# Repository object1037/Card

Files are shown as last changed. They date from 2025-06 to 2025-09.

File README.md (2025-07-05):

# Card

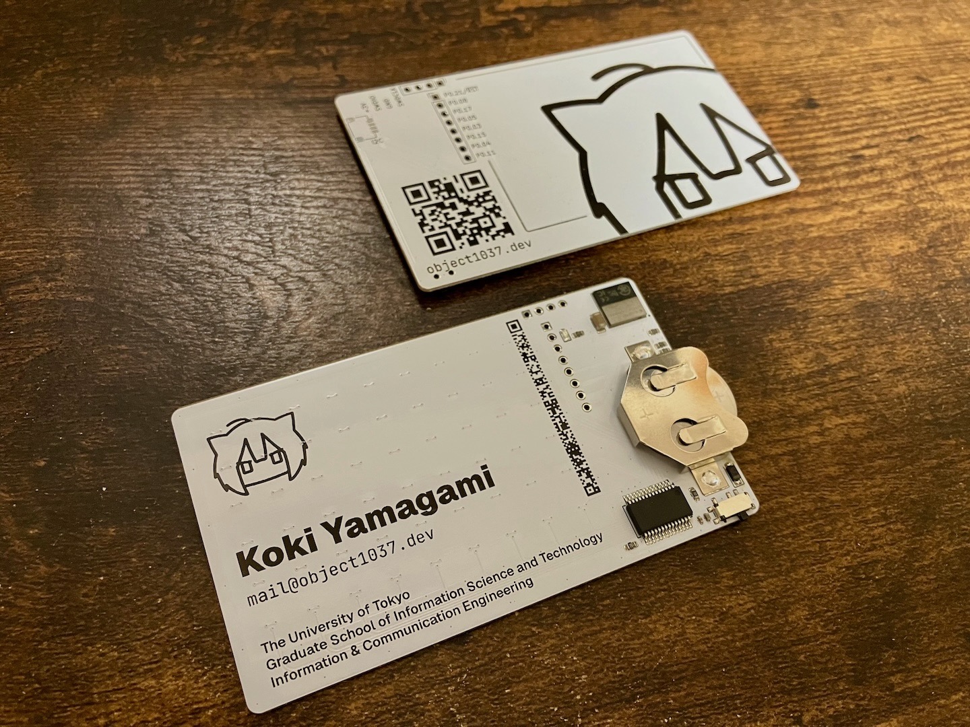
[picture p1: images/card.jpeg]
Photo of assembled cards


A PCB business card that functions as a Bluetooth trackpad.

* BLE module: [ISP1907-LL](https://www.insightsip.com/products/bluetooth-le-modules/isp1907) (SoC: nRF52811)
* Touch controller: [MTCH6102](https://www.microchip.com/en-us/product/mtch6102)
* Power: CR2032

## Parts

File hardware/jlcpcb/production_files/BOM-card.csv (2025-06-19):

Comment | Designator | Footprint | LCSC | Quantity
SW_SPDT | SW1 | SW_SPDT_PCM12 | C128955 | 1
100u | C3 | C_1206_3216Metric | C15008 | 1
0.1u | C1 | C_0402_1005Metric | C1525 | 1
10u | C2 | C_0402_1005Metric | C15525 | 1
LED | D2 | LED_0603_1608Metric | C2286 | 1
4.7k | R3,R4 | R_0603_1608Metric | C23162 | 2
1.8k | R1,R2 | R_0603_1608Metric | C4177 | 2
20k | R5 | R_0603_1608Metric | C4184 | 1
2.2k | R6 | R_0603_1608Metric | C4190 | 1
ISP1907 | U1 | ISP1907 | C5657569 | 1
MTCH6102 | U2 | SSOP-28_5.3x10.2mm_P0.65mm | C641630 | 1

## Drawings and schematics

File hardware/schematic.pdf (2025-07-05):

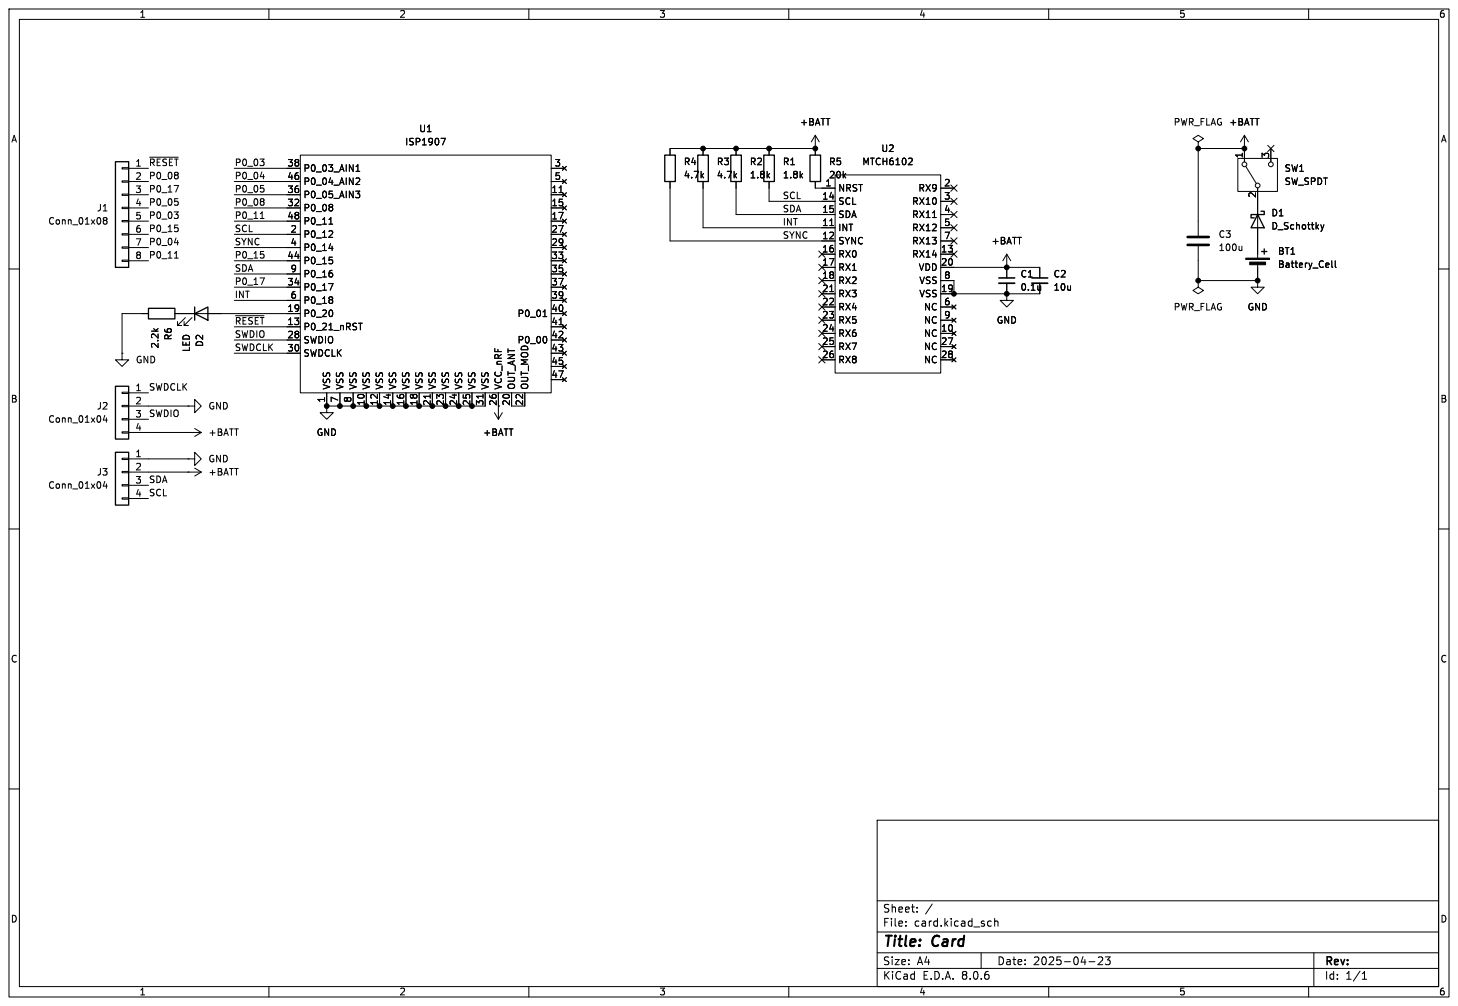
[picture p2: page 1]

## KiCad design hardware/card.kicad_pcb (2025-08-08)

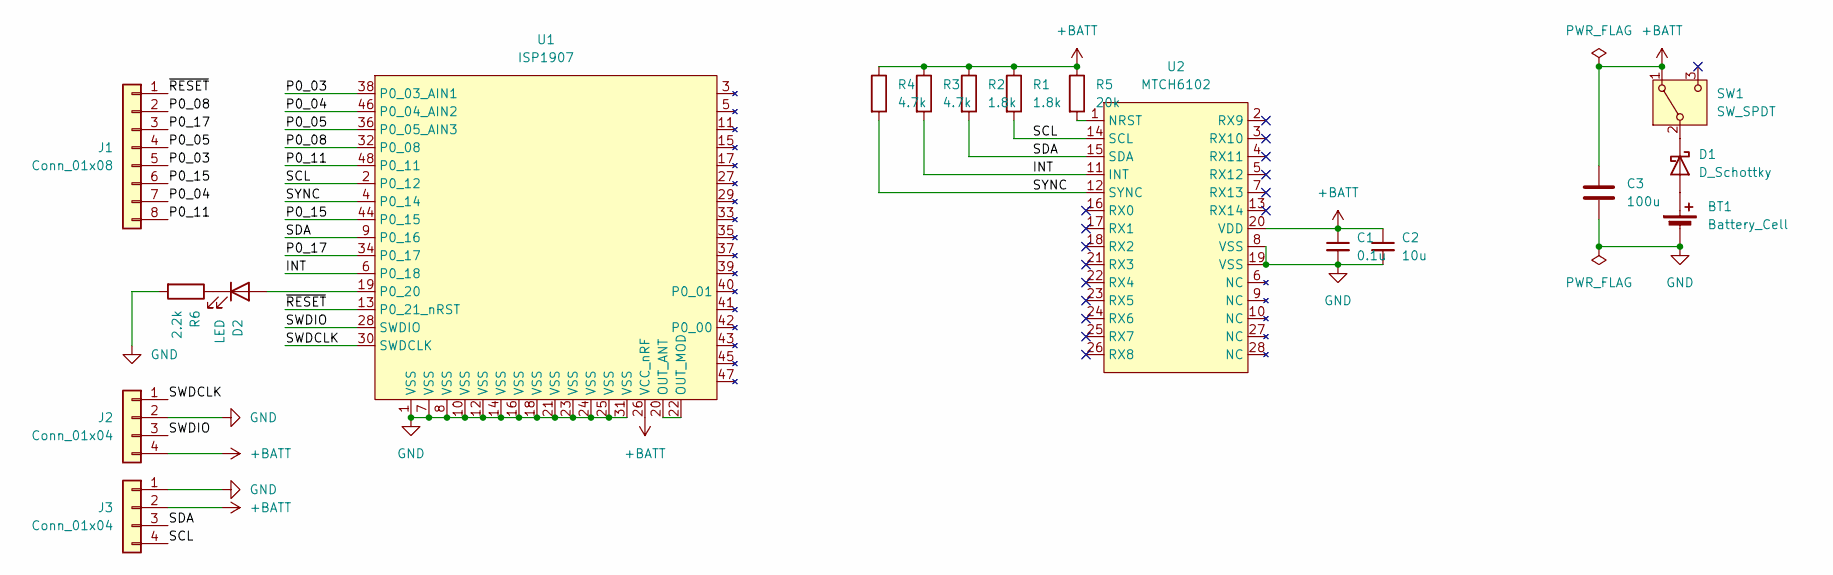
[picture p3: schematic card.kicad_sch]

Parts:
BT1: Battery_Cell; BatteryHolder_Multicomp_BC-2001_1x2032
C1: 0.1u; C_0402_1005Metric
C2: 10u; C_0402_1005Metric
C3: 100u; C_1206_3216Metric
D1: D_Schottky; D_SOD-123
D2: LED; LED_0603_1608Metric
J1: Conn_01x08; PinHeader_1x08_P2.54mm_Vertical
J2: Conn_01x04; PinHeader_1x04_P2.54mm_Vertical
J3: Conn_01x04; JST_SH_SM04B-SRSS-TB_1x04-1MP_P1.00mm_Horizontal
R1, R2: 1.8k; R_0603_1608Metric
R3, R4: 4.7k; R_0603_1608Metric
R5: 20k; R_0603_1608Metric
R6: 2.2k; R_0603_1608Metric
SW1: SW_SPDT; SW_SPDT_PCM12
U1: ISP1907
U2: MTCH6102; SSOP-28_5.3x10.2mm_P0.65mm

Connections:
+BATT: C1.1, C2.1, C3.1, J2.4, J3.2, R1.1, R2.1, R3.1, R4.1, R5.1, SW1.1 (A), U1.26 (VCC_nRF), U2.20 (VDD)
/INT: R3.2, U1.6 (P0_18), U2.11 (INT)
/P0_03: J1.5, U1.38 (P0_03_AIN1)
/P0_04: J1.7, U1.46 (P0_04_AIN2)
/P0_05: J1.4, U1.36 (P0_05_AIN3)
/P0_08: J1.2, U1.32 (P0_08)
/P0_11: J1.8, U1.48 (P0_11)
/P0_15: J1.6, U1.44 (P0_15)
/P0_17: J1.3, U1.34 (P0_17)
/SCL: J3.4, R1.2, U1.2 (P0_12), U2.14 (SCL)
/SDA: J3.3, R2.2, U1.9 (P0_16), U2.15 (SDA)
/SWDCLK: J2.1, U1.30 (SWDCLK)
/SWDIO: J2.3, U1.28 (SWDIO)
/SYNC: R4.2, U1.4 (P0_14), U2.12 (SYNC)
/~RESET: J1.1, U1.13 (P0_21_nRST)
GND: BT1.2 (-), C1.2, C2.2, C3.2, J2.2, J3.1, R6.2, U1.1 (VSS), U1.7 (VSS), U1.8 (VSS), U1.10 (VSS), U1.12 (VSS), U1.14 (VSS), U1.16 (VSS), U1.18 (VSS), U1.21 (VSS), U1.23 (VSS), U1.24 (VSS), U1.25 (VSS), U1.31 (VSS), U2.8 (VSS), U2.19 (VSS)
unnamed: BT1.1 (+), D1.2 (A)
unnamed: D1.1 (K), SW1.2 (B)
unnamed: D2.2 (A), U1.19 (P0_20)
unnamed: D2.1 (K), R6.1
unnamed: U1.20 (OUT_ANT), U1.22 (OUT_MOD)
unnamed: R5.2, U2.1 (NRST)

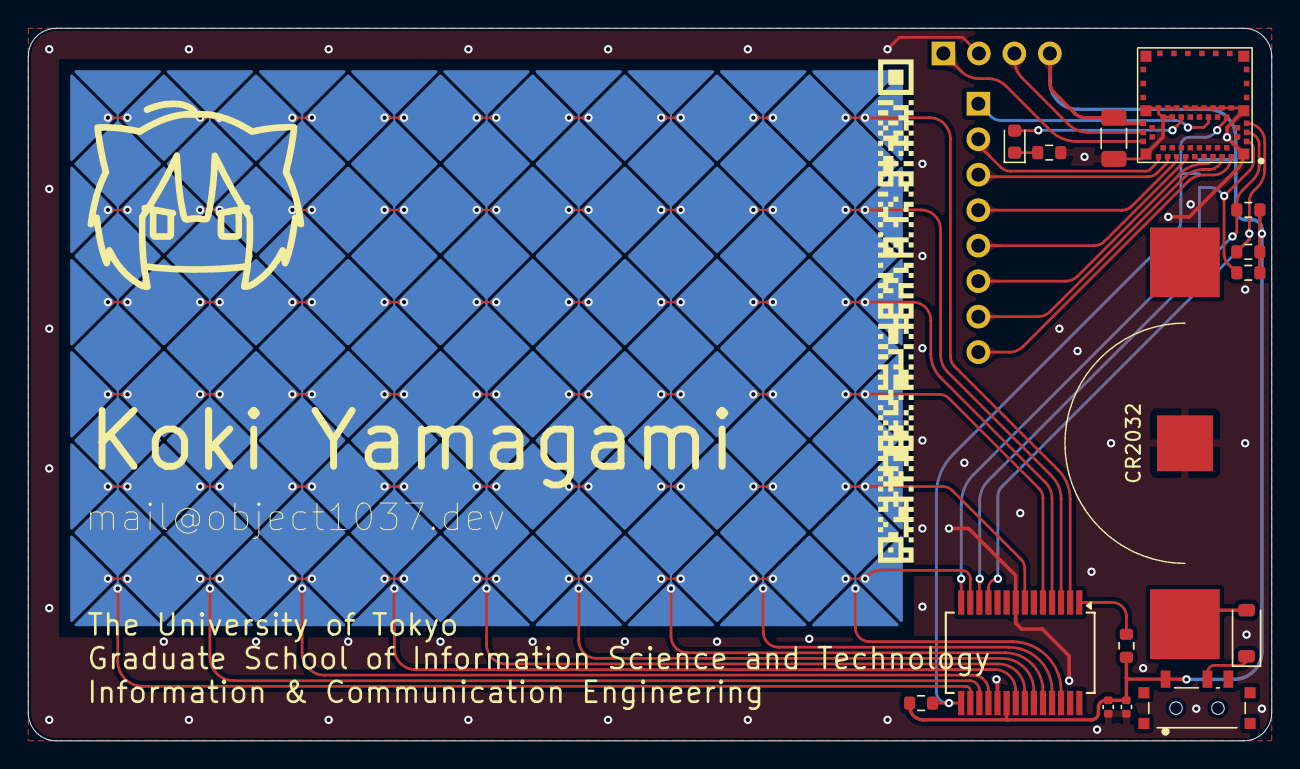
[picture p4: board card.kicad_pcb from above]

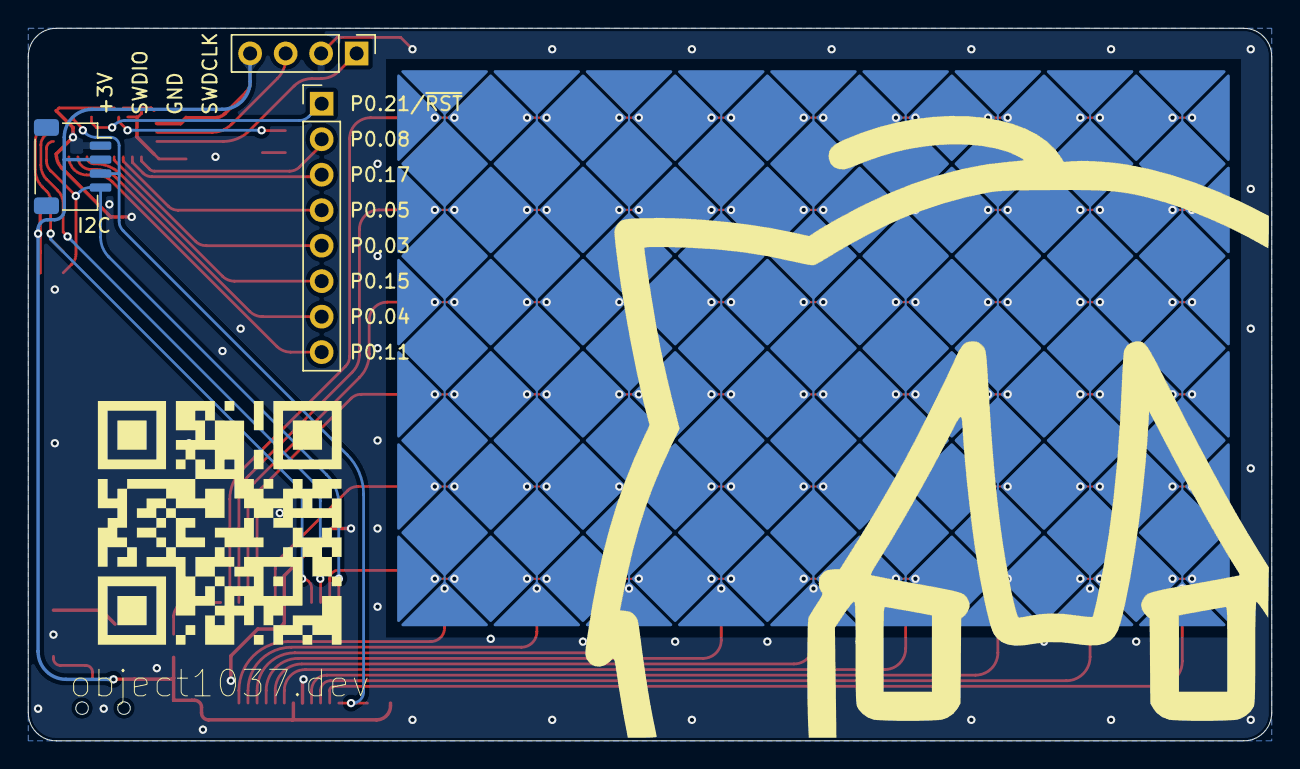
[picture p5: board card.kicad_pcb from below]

Board: 2 copper layers, 89.0 x 51.0 mm, 18 parts (3 on the bottom side), 22 nets.

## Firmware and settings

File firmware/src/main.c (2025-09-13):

#include <zephyr/kernel.h>
#include <zephyr/drivers/gpio.h>
#include <zephyr/drivers/i2c.h>
#include <zephyr/settings/settings.h>

#include <zephyr/bluetooth/bluetooth.h>
#include <zephyr/bluetooth/gap.h>
#include <zephyr/bluetooth/conn.h>
#include <bluetooth/services/hids.h>

#include <zephyr/pm/device.h>
#include <zephyr/sys/poweroff.h>

#include "mtch6102.h"

#define LED0_NODE DT_ALIAS(led0)
#define INT0_NODE DT_ALIAS(int0)
#define I2C0_NODE DT_ALIAS(trackpad0)

#define DEVICE_NAME_LEN (sizeof(CONFIG_BT_DEVICE_NAME) - 1)

static void mouse_handler(struct k_work *work);
static void adv_work_handler(struct k_work *work);
static void trackpad_work_handler(struct k_work *work);
static void pointer_movement_send(int16_t x_delta, int16_t y_delta, gesture_t gesture);

static struct pos_gesture {
  int16_t x_val;
  int16_t y_val;
  gesture_t gesture;
} posi_gest;
static struct pos_gesture delta_ges_reset = {0};
static struct pos_gesture delta_ges_click = {0, 0, 1};
static bool is_touched = false;

static struct bt_conn *connection;
static bool in_boot_mode;
static volatile bool is_adv_running = false;

BT_HIDS_DEF(hids_obj, 3);

K_MSGQ_DEFINE(hids_queue, sizeof(struct pos_gesture), 5, 1);

static K_WORK_DEFINE(hids_work, mouse_handler);
static K_WORK_DEFINE(adv_work, adv_work_handler);
static K_WORK_DEFINE(trackpad_work, trackpad_work_handler);

static const struct gpio_dt_spec led = GPIO_DT_SPEC_GET(LED0_NODE, gpios);
static const struct gpio_dt_spec int_pin = GPIO_DT_SPEC_GET(INT0_NODE, gpios);
static const struct i2c_dt_spec trackpad = I2C_DT_SPEC_GET(I2C0_NODE);

static struct gpio_callback int_cb_data;

static const struct bt_data ad[] = {
    BT_DATA_BYTES(BT_DATA_GAP_APPEARANCE, (BT_APPEARANCE_HID_TOUCHPAD >> 0) & 0xFF, (BT_APPEARANCE_HID_TOUCHPAD >> 8) & 0xFF),
    BT_DATA_BYTES(BT_DATA_FLAGS, (BT_LE_AD_GENERAL | BT_LE_AD_NO_BREDR)),
    BT_DATA_BYTES(BT_DATA_UUID16_ALL, BT_UUID_16_ENCODE(BT_UUID_HIDS_VAL)),
};

static const struct bt_data sd[] = {
    BT_DATA(BT_DATA_NAME_COMPLETE, CONFIG_BT_DEVICE_NAME, DEVICE_NAME_LEN),
};

static void mouse_handler(struct k_work *work) {
  struct pos_gesture pos_ges;

  while (!k_msgq_get(&hids_queue, &pos_ges, K_NO_WAIT)) {
    pointer_movement_send(pos_ges.x_val, pos_ges.y_val, pos_ges.gesture);
  }
}

static void adv_work_handler(struct k_work *work) {
  if (is_adv_running) return;

  int ret = bt_le_adv_start(BT_LE_ADV_CONN_FAST_2, ad, ARRAY_SIZE(ad), sd, ARRAY_SIZE(sd));
  if (ret) return;
  is_adv_running = true;
}

static void trackpad_work_handler(struct k_work *work) {
  int ret;
  int16_t x_new, y_new;
  struct pos_gesture delta_ges = {0};

  bool was_touched = is_touched;

  // flip x/y here
  ret = get_touch_data(&trackpad, &y_new, &x_new, &is_touched, &delta_ges.gesture);
  if (ret < 0) return;

  y_new = TOUCH_X_MAX - y_new;

  if (!was_touched && is_touched) {
    posi_gest.x_val = x_new;
    posi_gest.y_val = y_new;
  } else if (was_touched && is_touched) {
    delta_ges.x_val = x_new - posi_gest.x_val;
    delta_ges.y_val = y_new - posi_gest.y_val;

    if (delta_ges.x_val || delta_ges.y_val) {
      posi_gest.x_val = x_new;
      posi_gest.y_val = y_new;
    }
  }

  if (delta_ges.x_val == 0 && delta_ges.y_val == 0 && delta_ges.gesture == posi_gest.gesture) {
    return;
  }

  posi_gest.gesture = delta_ges.gesture;

  ret = k_msgq_put(&hids_queue, &delta_ges, K_NO_WAIT);
  if (ret) return;

  if (k_msgq_num_used_get(&hids_queue) == 1) {
    k_work_submit(&hids_work);
  }
}

static void hids_pm_evt_handler(enum bt_hids_pm_evt evt, struct bt_conn *conn) {
  switch (evt) {
    case BT_HIDS_PM_EVT_BOOT_MODE_ENTERED:
      in_boot_mode = true;
      break;

    case BT_HIDS_PM_EVT_REPORT_MODE_ENTERED:
      in_boot_mode = false;
      break;

    default:
      break;
  }
}

static void hid_init(void) {
  int ret;
  struct bt_hids_init_param hids_init_param = {0};
  struct bt_hids_inp_rep *hids_inp_rep;

  static const uint8_t report_map[] = {
      0x05, 0x01, /* Usage Page (Generic Desktop) */
      0x09, 0x02, /* Usage (Mouse) */

      0xA1, 0x01, /* Collection (Application) */

      0x09, 0x01,       /* Usage (Pointer) */
      0xA1, 0x00,       /* Collection (Physical) */
      0x05, 0x01,       /* Usage Page (Generic Desktop) */
      0x09, 0x30,       /* Usage (X) */
      0x09, 0x31,       /* Usage (Y) */
      0x16, 0x01, 0xFE, /* Logical minimum (-511) */
      0x26, 0xFF, 0x01, /* Logical maximum (511) */
      0x75, 0x0A,       /* Report Size (10) */
      0x95, 0x02,       /* Report Count (2) */
      0x81, 0x06,       /* Input (Data, Variable, Relative) */

      0x05, 0x09, /* Usage Page (Buttons) */
      0x19, 0x01, /* Usage Minimum (01) */
      0x29, 0x03, /* Usage Maximum (03) */
      0x15, 0x00, /* Logical Minimum (0) */
      0x25, 0x01, /* Logical Maximum (1) */
      0x75, 0x01, /* Report Size (1) */
      0x95, 0x03, /* Report Count (3) */
      0x81, 0x02, /* Input (Data, Variable, Absolute) */
      0x75, 0x01, /* Report Size (1) */
      0x95, 0x01, /* Report Count (1) */
      0x81, 0x01, /* Input (Constant) for padding */
      0xC0,       /* End Collection (Physical) */
      0xC0,       /* End Collection (Application) */
  };

  hids_init_param.rep_map.data = report_map;
  hids_init_param.rep_map.size = sizeof(report_map);

  hids_init_param.info.bcd_hid = 0x0111;       // HID version 1.11
  hids_init_param.info.b_country_code = 0x00;  // No localization
  hids_init_param.info.flags = (BT_HIDS_REMOTE_WAKE | BT_HIDS_NORMALLY_CONNECTABLE);

  hids_inp_rep = &hids_init_param.inp_rep_group_init.reports[0];
  hids_inp_rep->size = 3;
  hids_inp_rep->id = 0;
  hids_init_param.inp_rep_group_init.cnt++;

  hids_init_param.is_mouse = true;
  hids_init_param.pm_evt_handler = hids_pm_evt_handler;

  ret = bt_hids_init(&hids_obj, &hids_init_param);
}

static void pointer_movement_send(int16_t x_delta, int16_t y_delta, gesture_t gesture) {
  if (!connection) return;

  x_delta = MAX(MIN(x_delta, 511), -511);
  y_delta = MAX(MIN(y_delta, 511), -511);

  uint8_t buttons = 0;

  switch (gesture) {
    case GESTURE_CLICK:
      buttons |= 0x01;
      k_msgq_put(&hids_queue, &delta_ges_reset, K_NO_WAIT);
      break;
    case GESTURE_CLICK_HOLD:
      buttons |= 0x02;
      break;
    case GESTURE_DOUBLE_CLICK:
      buttons |= 0x01;
      k_msgq_put(&hids_queue, &delta_ges_reset, K_NO_WAIT);
      k_msgq_put(&hids_queue, &delta_ges_click, K_NO_WAIT);
      k_msgq_put(&hids_queue, &delta_ges_reset, K_NO_WAIT);
      break;
    default:
      break;
  }

  if (in_boot_mode) {
    bt_hids_boot_mouse_inp_rep_send(&hids_obj, connection, &buttons, (int8_t)x_delta, (int8_t)y_delta, NULL);
  } else {
    uint8_t buffer[3];

    uint16_t ux = (uint16_t)(x_delta & 0x03FF);
    uint16_t uy = (uint16_t)(y_delta & 0x03FF);

    buffer[0] = (uint8_t)(ux & 0xFF);
    buffer[1] = (uint8_t)(((ux >> 8) & 0x03) | ((uy & 0x3F) << 2));
    buffer[2] = (uint8_t)(((uy >> 6) & 0x0F) | (buttons << 4));

    bt_hids_inp_rep_send(&hids_obj, connection, 0, buffer, sizeof(buffer), NULL);
  }
}

static void advertising_start(void) {
  k_work_submit(&adv_work);
}

static void on_connected(struct bt_conn *conn, uint8_t err) {
  is_adv_running = false;
  if (err) return;

  err = bt_hids_connected(&hids_obj, conn);
  if (err) return;

  connection = conn;
  in_boot_mode = false;

  gpio_pin_set_dt(&led, 1);
  k_msleep(500);
  gpio_pin_set_dt(&led, 0);
}

static void on_disconnected(struct bt_conn *conn, uint8_t reason) {
  bt_hids_disconnected(&hids_obj, conn);

  connection = NULL;

  advertising_start();
}

void on_recycled(void) {
  advertising_start();
}

static void pairing_complete(struct bt_conn *conn, bool bonded) {
  gpio_pin_set_dt(&led, 1);
  k_msleep(250);
  gpio_pin_set_dt(&led, 0);
}

static void pairing_failed(struct bt_conn *conn, enum bt_security_err reason) {
  for (size_t i = 0; i < 3; i++) {
    gpio_pin_set_dt(&led, 0);
    k_msleep(200);
    gpio_pin_set_dt(&led, 1);
    k_msleep(200);
  }
  gpio_pin_set_dt(&led, 0);
  return;
}

static void int_callback(const struct device *dev, struct gpio_callback *cb, uint32_t pins) {
  k_work_submit(&trackpad_work);
}

static struct bt_conn_cb connection_callbacks = {
    .connected = on_connected,
    .disconnected = on_disconnected,
    .recycled = on_recycled,
};

static struct bt_conn_auth_info_cb conn_auth_info_callbacks = {
    .pairing_complete = pairing_complete,
    .pairing_failed = pairing_failed,
};

int main(void) {
  int ret;

  if (!gpio_is_ready_dt(&led)) return 0;
  ret = gpio_pin_configure_dt(&led, GPIO_OUTPUT_INACTIVE);
  if (ret < 0) return 0;

  if (!gpio_is_ready_dt(&int_pin)) return 0;
  ret = gpio_pin_configure_dt(&int_pin, GPIO_INPUT);
  if (ret < 0) return 0;
  ret = gpio_pin_interrupt_configure_dt(&int_pin, GPIO_INT_EDGE_FALLING);
  if (ret < 0) return 0;

  ret = bt_conn_cb_register(&connection_callbacks);
  if (ret < 0) return 0;
  ret = bt_conn_auth_cb_register(NULL);
  if (ret < 0) return 0;
  ret = bt_conn_auth_info_cb_register(&conn_auth_info_callbacks);
  if (ret < 0) return 0;

  gpio_init_callback(&int_cb_data, int_callback, BIT(int_pin.pin));
  gpio_add_callback(int_pin.port, &int_cb_data);

  hid_init();

  ret = bt_enable(NULL);
  if (ret < 0) return 0;

  settings_load();
  advertising_start();

  if (!device_is_ready(trackpad.bus)) return 0;

  ret = init_mtch6102(&trackpad);
  if (ret < 0) return 0;

  return 0;
}

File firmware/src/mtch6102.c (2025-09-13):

#include "mtch6102.h"

static int apply_config(const struct i2c_dt_spec *trackpad) {
  int ret;

  uint8_t cmd = CMD_CFG;
  ret = i2c_reg_write_byte_dt(trackpad, CMD_ADDR, cmd);
  if (ret < 0) return -1;

  return 0;
}

int init_mtch6102(const struct i2c_dt_spec *trackpad) {
  int ret;

  uint8_t idle_period_h = 0x0c;
  uint8_t idle_period_l = 0x99;  // 100 ms
  uint8_t tap_hold_time_h = 0x27;
  uint8_t tap_hold_time_l = 0x10;// 2 s

  ret = i2c_reg_write_byte_dt(trackpad, IDLE_PERIOD_L_ADDR, idle_period_l);
  if (ret < 0) return -1;
  ret = i2c_reg_write_byte_dt(trackpad, IDLE_PERIOD_H_ADDR, idle_period_h);
  if (ret < 0) return -1;
  ret = i2c_reg_write_byte_dt(trackpad, TAP_HOLD_TIME_L_ADDR, tap_hold_time_l);
  if (ret < 0) return -1;
  ret = i2c_reg_write_byte_dt(trackpad, TAP_HOLD_TIME_H_ADDR, tap_hold_time_h);
  if (ret < 0) return -1;

  ret = apply_config(trackpad);

  return ret;
}

int get_touch_data(
  const struct i2c_dt_spec *trackpad,
  uint16_t *touch_x,
  uint16_t *touch_y,
  bool *is_touched,
  gesture_t *gesture
) {
  int ret;
  uint8_t touch_data[5] = {0};

  ret = i2c_burst_read_dt(trackpad, TOUCH_STATE_ADDR, touch_data, sizeof(touch_data));
  if (ret < 0) return -1;

  *is_touched = (touch_data[0] & STATE_TOUCH_BM) != 0;

  *touch_x = ((touch_data[1] << 4) | (touch_data[3] >> 4));
  *touch_y = (touch_data[2] << 4) | (touch_data[3] & 0x0F);

  *gesture = (gesture_t)touch_data[4];

  return 0;
}

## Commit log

2025-06-06 update isp1907 symbol
    [card.kicad_sch]
2025-06-07 basic schematic
    [card.kicad_sch]
2025-06-07 basic pcb layout
    [card.kicad_pcb, card.kicad_sch]
2025-06-10 add qwiic conn and fillet traces
    [card.kicad_pcb, card.kicad_sch]
2025-06-10 update zone setting
    [card.kicad_pcb]
2025-06-13 update silk
    [card.kicad_pcb]
2025-06-13 add esd guard
    [card.kicad_pcb]
2025-06-15 plot gerber
    [card-B_Cu.gbr, card-B_Mask.gbr, card-B_Paste.gbr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]
2025-06-19 add switch
    [card.kicad_pcb, card.kicad_sch]
2025-06-19 update production files
    [BOM-card.csv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]
2025-06-19 add teardrops
    [card-CuBottom.gbr, card-CuTop.gbr, card-EdgeCuts.gbr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]
2025-06-26 organize folder
    [BOM-card.csv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]
2025-06-30 LED blink
2025-06-30 interrupt test
2025-07-05 update schematic pdf
2025-08-07 update kicad version
    [card.kicad_pcb, card.kicad_sch]
2025-08-08 prepare for interrupt-base operation
    [card.kicad_pcb]
2025-08-08 move board defconfig to Kconfig.defconfig
2025-08-08 use work to offload led toggle from isr
2025-08-08 handle i2c in work handler
